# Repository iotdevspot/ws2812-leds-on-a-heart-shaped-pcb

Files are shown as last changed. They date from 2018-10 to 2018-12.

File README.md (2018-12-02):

# ws2812-leds-on-a-heart-shaped-pcb

### About the project
This is a WS2812 LED driver circuit with an ATTiny85 MCU. PCB and the LEDs are aligned to create a heart shape because it's a gift.  Unfortunately, I'm quite sort of time so the code is very basic and it has been created from the examples found on Adafruit's website. In the future I'll upload a newer version. This version is only capable for 4 basic effects witch can be selected with the left function button.

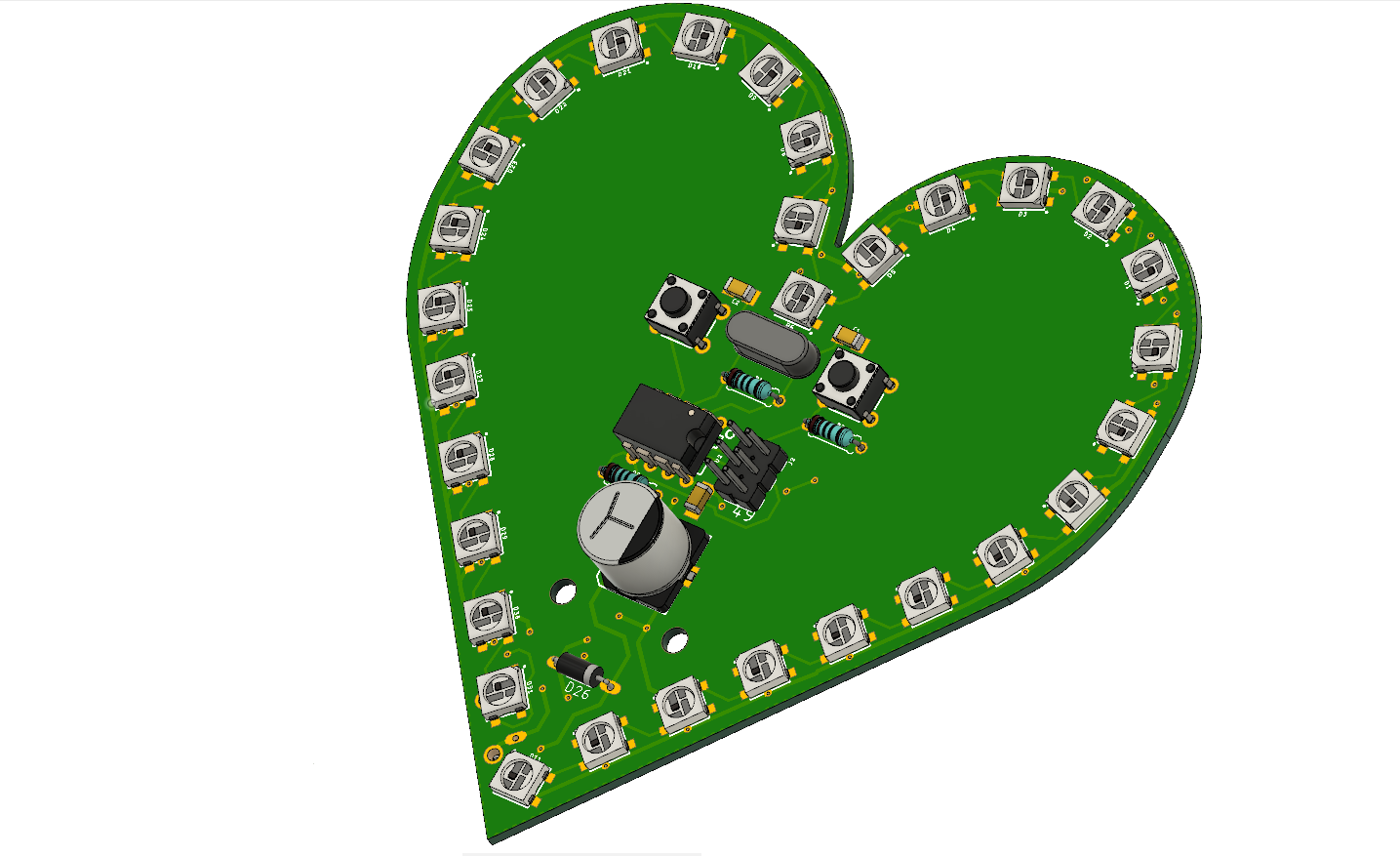
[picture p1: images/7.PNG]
image of the pcb


### Contents
* Gerber files (the version that I've sent to the fab house)
* Updated board layout and schematics
* 3D model can be found on my fusion360 gallery
* Code (Arduino sketch and hex)
* Datasheet
* Images of the result

### The following steps are required to deploy the provided .hex, or the Arduino sketch:
* Here is how to program ATTiny MCUs in Arduino IDE: [link](http://highlowtech.org/?p=1695)
* I've used external 16 MHz oscillator (AVR fuse settings needed + hex is compiled this way too) so it might be required but I assume it works on internal clock well too but code should be recompiled
* Code is based on Adafruit's [Neopixel libary and their example projects](https://learn.adafruit.com/adafruit-arduino-lesson-16-stepper-motors/breadboard-layout) so Adafruit's libary might be needed if you want to deploy it from the IDE.
* Finnaly the hex should be uploaded. You can do this by using IDE-s "Upload using programmer" option or .hex file can be uploaded throuh AVR Dude too. It's basically your choice...

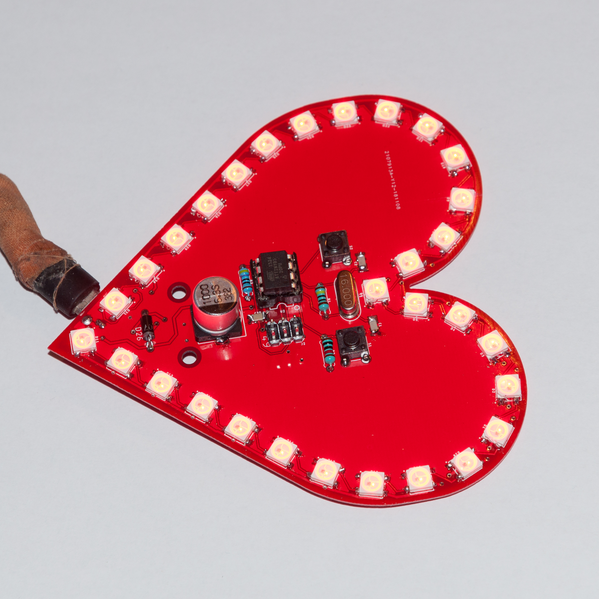
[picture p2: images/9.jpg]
image of the pcb


### ToDo

* 3D printed mounting for the two mounting holes
* Replace the full bascic code

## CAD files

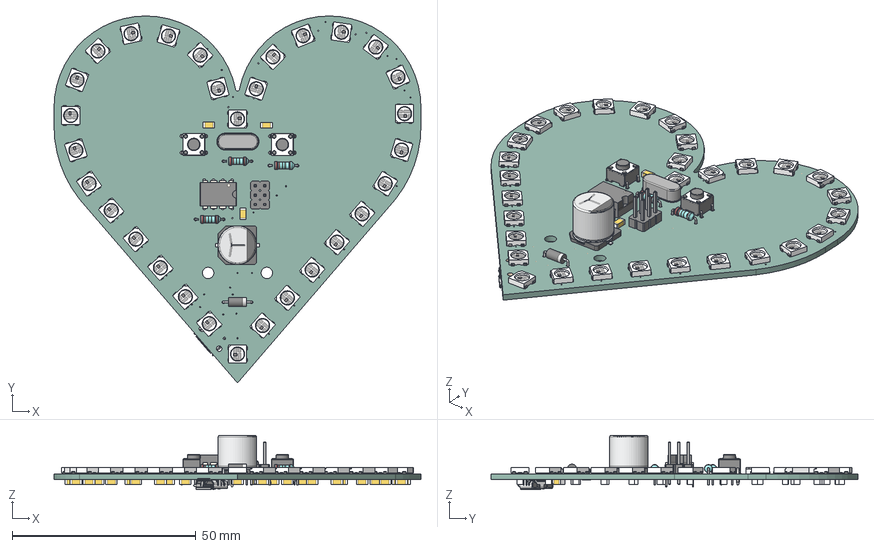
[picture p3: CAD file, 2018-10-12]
heart-shaped-smd-light-gift v12.step
100.0 x 100.0 x 14.8 mm
Board
100 nF x 33
WS2812B x 30
CONN_AVR_SPI_PROG_3X2PTH
CONN_USB_MICRO_FEM_GDND
D-7.5
16MHz
1000 uF
INPUT_MOMENTARY_SWITCH_SPST-PTH-6.0MM x 2
TINY45-20-DIP
SNAP-MALE x 2

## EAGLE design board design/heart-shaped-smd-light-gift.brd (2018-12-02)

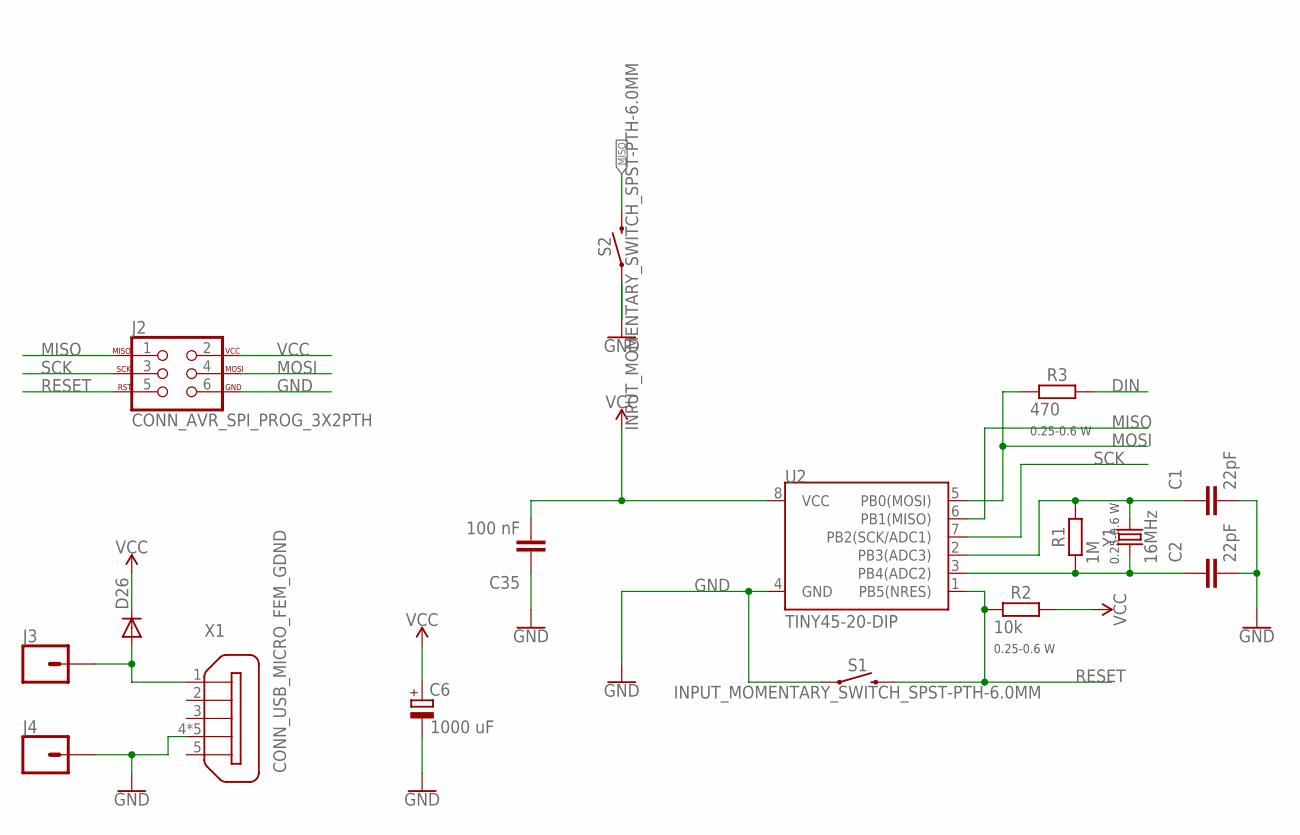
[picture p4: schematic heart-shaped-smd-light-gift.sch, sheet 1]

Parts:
C1, C2: 22pF; C1206I-C3216M
C6: 1000 uF; 153CLV-1010
C35: 100 nF; C1206I-C3216M
D26: DIODED-7.5; D-7.5
J2: CONN_AVR_SPI_PROG_3X2PTH; 2X3_S
J3, J4: CONN_01SNAP-MALE; SNAP-MALE
R1: 1M; 0207/7
R2: 10k; 0207/7
R3: 470; 0207/7
S1, S2: INPUT_MOMENTARY_SWITCH_SPST-PTH-6.0MM; TACTILE_SWITCH_PTH_6.0MM
U2: TINY45-20-DIP; DIP08
X1: CONN_USB_MICRO_FEM_GDND; ZX62D-B-5PA8
Y1: 16MHz; HC49US

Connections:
DIN: R3.2; also elsewhere on the board
GND: C1.2, C2.2, C6.-, C35.1, J2.6, J4.2, S1.1, S2.1, U2.4 (GND), X1.4, X1.S1 (4), X1.S2 (4), X1.S3 (4), X1.S4 (4); also elsewhere on the board
MISO: J2.1, S2.3 (2), U2.6 (PB1(MISO))
MOSI: J2.4, R3.1, U2.5 (PB0(MOSI))
unnamed: C2.1, R1.1, U2.3 (PB4(ADC2)), Y1.1
unnamed: C1.1, R1.2, U2.2 (PB3(ADC3)), Y1.2
unnamed: D26.A, J3.2, X1.1
RESET: J2.5, R2.1, S1.3 (2), U2.1 (PB5(NRES))
SCK: J2.3, U2.7 (PB2(SCK/ADC1))
VCC: C6.+, C35.2, D26.C, J2.2, R2.2, U2.8 (VCC); also elsewhere on the board

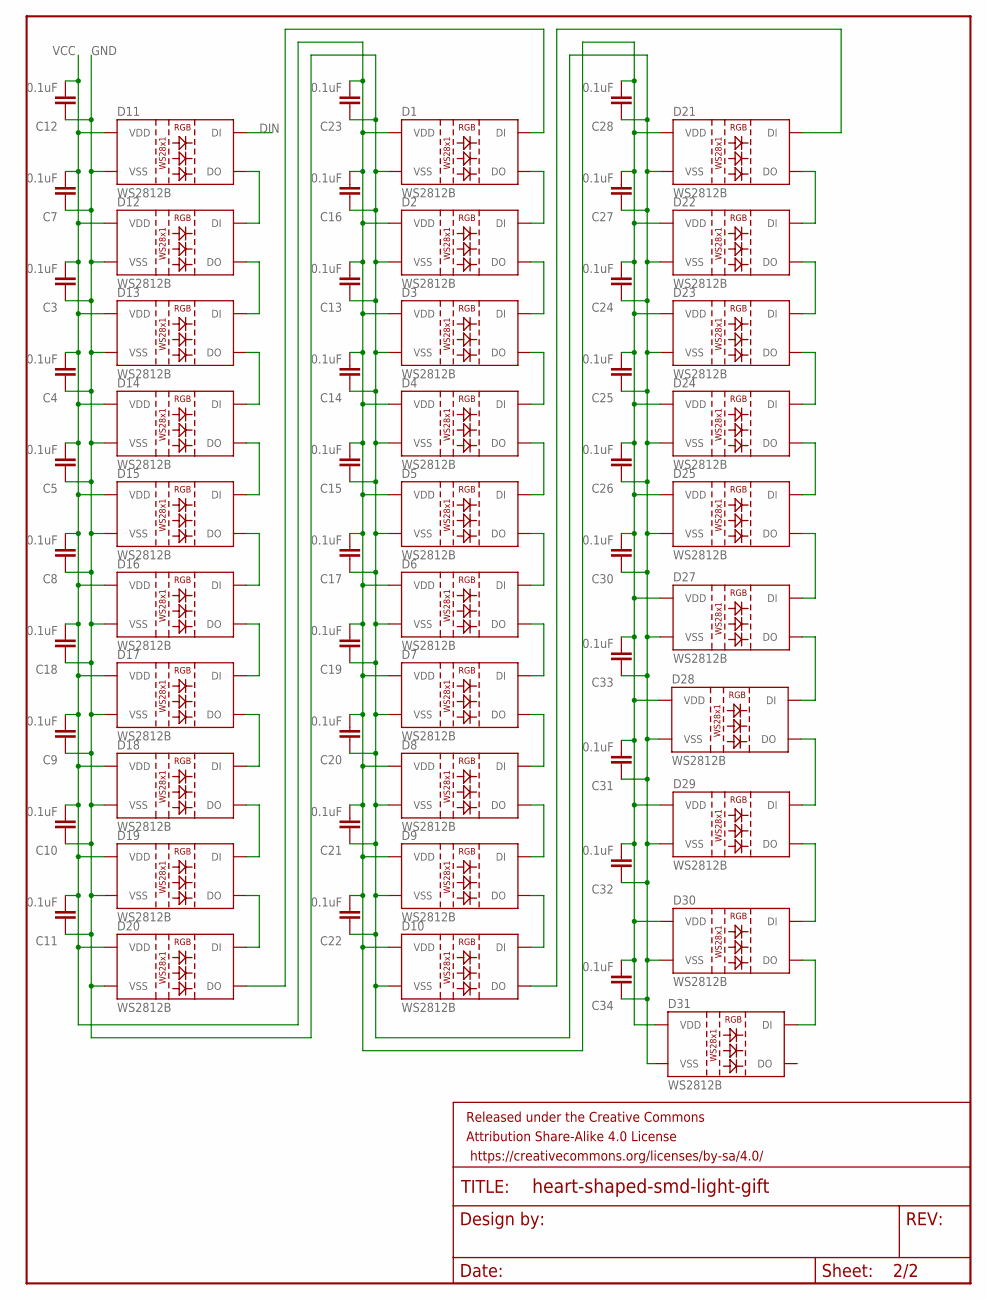
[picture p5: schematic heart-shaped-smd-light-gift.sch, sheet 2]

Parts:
C3, C4, C5, C7, C8, C9, C10, C11, C12, C13, C14, C15, C16, C17, C18, C19, C20, C21, C22, C23, C24, C25, C26, C27, C28, C30, C31, C32, C33, C34: 0.1uF; C1206I-C3216M
D1, D2, D3, D4, D5, D6, D7, D8, D9, D10, D11, D12, D13, D14, D15, D16, D17, D18, D19, D20, D21, D22, D23, D24, D25, D27, D28, D29, D30, D31: WS2812B
FRAME2: FRAME_LETTERNO_PACKAGE; DUMMY

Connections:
DIN: D11.4 (DI); also elsewhere on the board
DIN2: D10.2 (DO), D21.4 (DI)
GND: C3.1, C4.1, C5.1, C7.1, C8.1, C9.1, C10.1, C11.1, C12.1, C13.1, C14.1, C15.1, C16.1, C17.1, C18.1, C19.1, C20.1, C21.1, C22.1, C23.1, C24.1, C25.1, C26.1, C27.1, C28.1, C30.1, C31.1, C32.1, C33.1, C34.1, D1.3 (VSS), D2.3 (VSS), D3.3 (VSS), D4.3 (VSS), D5.3 (VSS), D6.3 (VSS), D7.3 (VSS), D8.3 (VSS), D9.3 (VSS), D10.3 (VSS), D11.3 (VSS), D12.3 (VSS), D13.3 (VSS), D14.3 (VSS), D15.3 (VSS), D16.3 (VSS), D17.3 (VSS), D18.3 (VSS), D19.3 (VSS), D20.3 (VSS), D21.3 (VSS), D22.3 (VSS), D23.3 (VSS), D24.3 (VSS), D25.3 (VSS), D27.3 (VSS), D28.3 (VSS), D29.3 (VSS), D30.3 (VSS), D31.3 (VSS); also elsewhere on the board
unnamed: D18.2 (DO), D19.4 (DI)
unnamed: D1.2 (DO), D2.4 (DI)
unnamed: D2.2 (DO), D3.4 (DI)
unnamed: D3.2 (DO), D4.4 (DI)
unnamed: D4.2 (DO), D5.4 (DI)
unnamed: D5.2 (DO), D6.4 (DI)
unnamed: D11.2 (DO), D12.4 (DI)
unnamed: D6.2 (DO), D7.4 (DI)
unnamed: D12.2 (DO), D13.4 (DI)
unnamed: D7.2 (DO), D8.4 (DI)
unnamed: D8.2 (DO), D9.4 (DI)
unnamed: D9.2 (DO), D10.4 (DI)
unnamed: D1.4 (DI), D20.2 (DO)
unnamed: D21.2 (DO), D22.4 (DI)
unnamed: D13.2 (DO), D14.4 (DI)
unnamed: D14.2 (DO), D15.4 (DI)
unnamed: D22.2 (DO), D23.4 (DI)
unnamed: D15.2 (DO), D16.4 (DI)
unnamed: D16.2 (DO), D17.4 (DI)
unnamed: D17.2 (DO), D18.4 (DI)
unnamed: D19.2 (DO), D20.4 (DI)
unnamed: D23.2 (DO), D24.4 (DI)
unnamed: D24.2 (DO), D25.4 (DI)
unnamed: D25.2 (DO), D27.4 (DI)
unnamed: D27.2 (DO), D28.4 (DI)
unnamed: D28.2 (DO), D29.4 (DI)
unnamed: D29.2 (DO), D30.4 (DI)
unnamed: D30.2 (DO), D31.4 (DI)
VCC: C3.2, C4.2, C5.2, C7.2, C8.2, C9.2, C10.2, C11.2, C12.2, C13.2, C14.2, C15.2, C16.2, C17.2, C18.2, C19.2, C20.2, C21.2, C22.2, C23.2, C24.2, C25.2, C26.2, C27.2, C28.2, C30.2, C31.2, C32.2, C33.2, C34.2, D1.1 (VDD), D2.1 (VDD), D3.1 (VDD), D4.1 (VDD), D5.1 (VDD), D6.1 (VDD), D7.1 (VDD), D8.1 (VDD), D9.1 (VDD), D10.1 (VDD), D11.1 (VDD), D12.1 (VDD), D13.1 (VDD), D14.1 (VDD), D15.1 (VDD), D16.1 (VDD), D17.1 (VDD), D18.1 (VDD), D19.1 (VDD), D20.1 (VDD), D21.1 (VDD), D22.1 (VDD), D23.1 (VDD), D24.1 (VDD), D25.1 (VDD), D27.1 (VDD), D28.1 (VDD), D29.1 (VDD), D30.1 (VDD), D31.1 (VDD); also elsewhere on the board

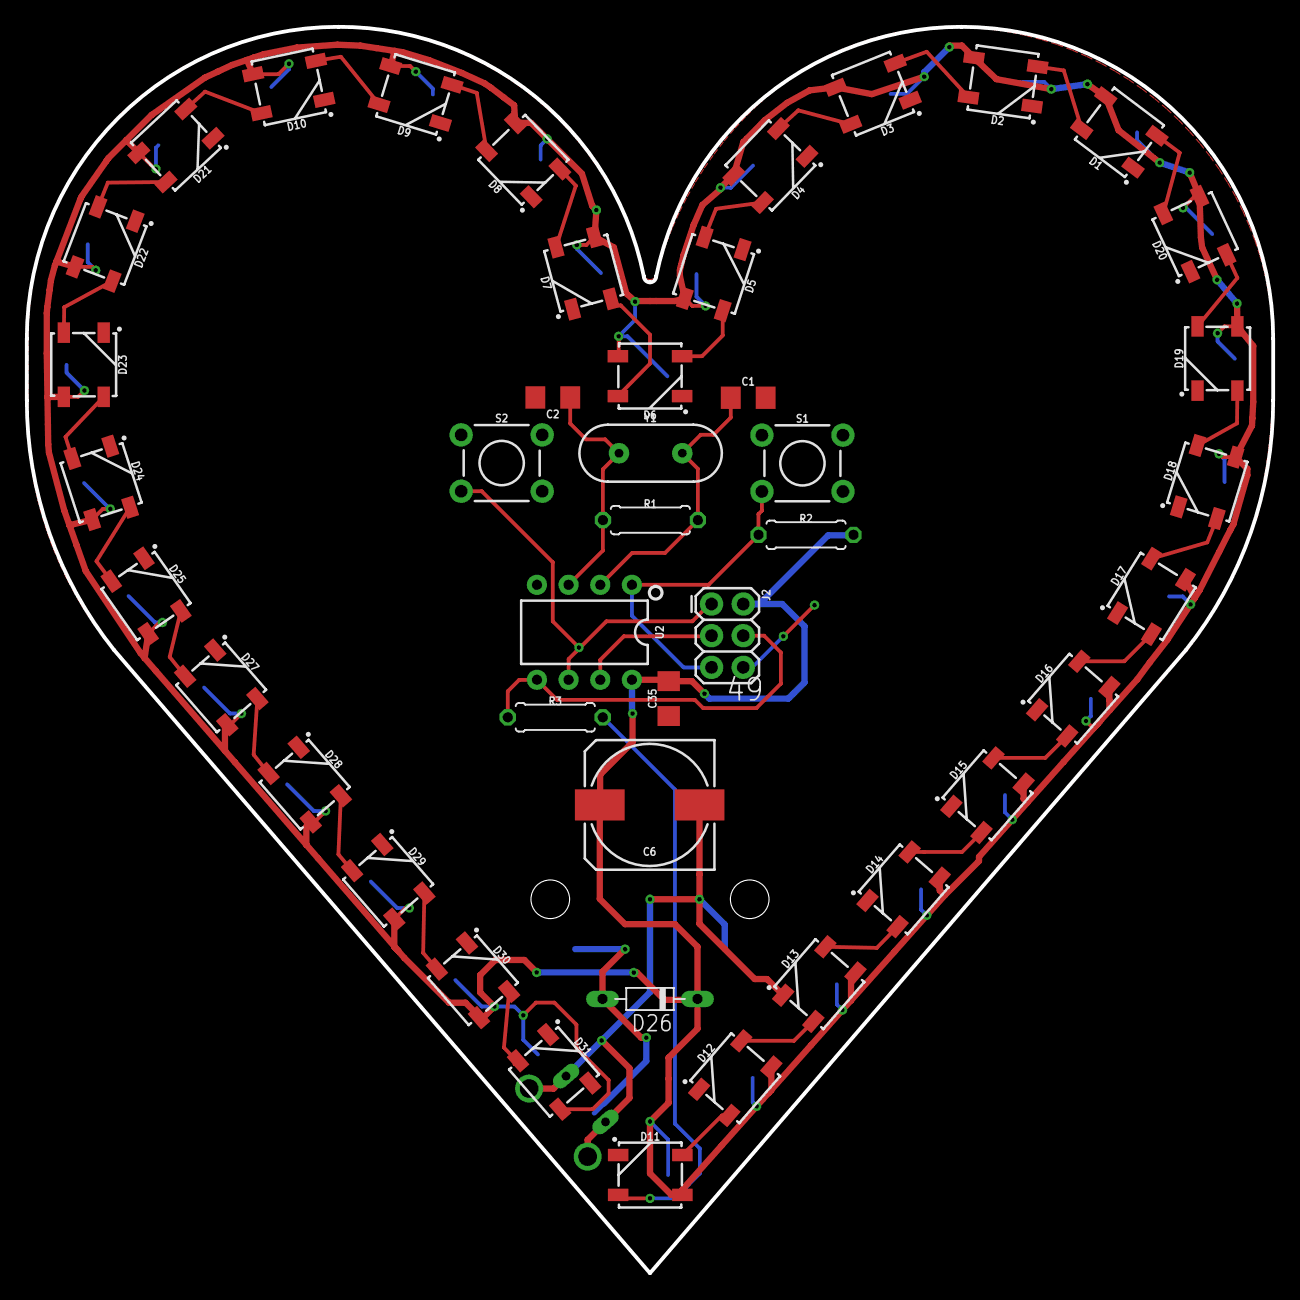
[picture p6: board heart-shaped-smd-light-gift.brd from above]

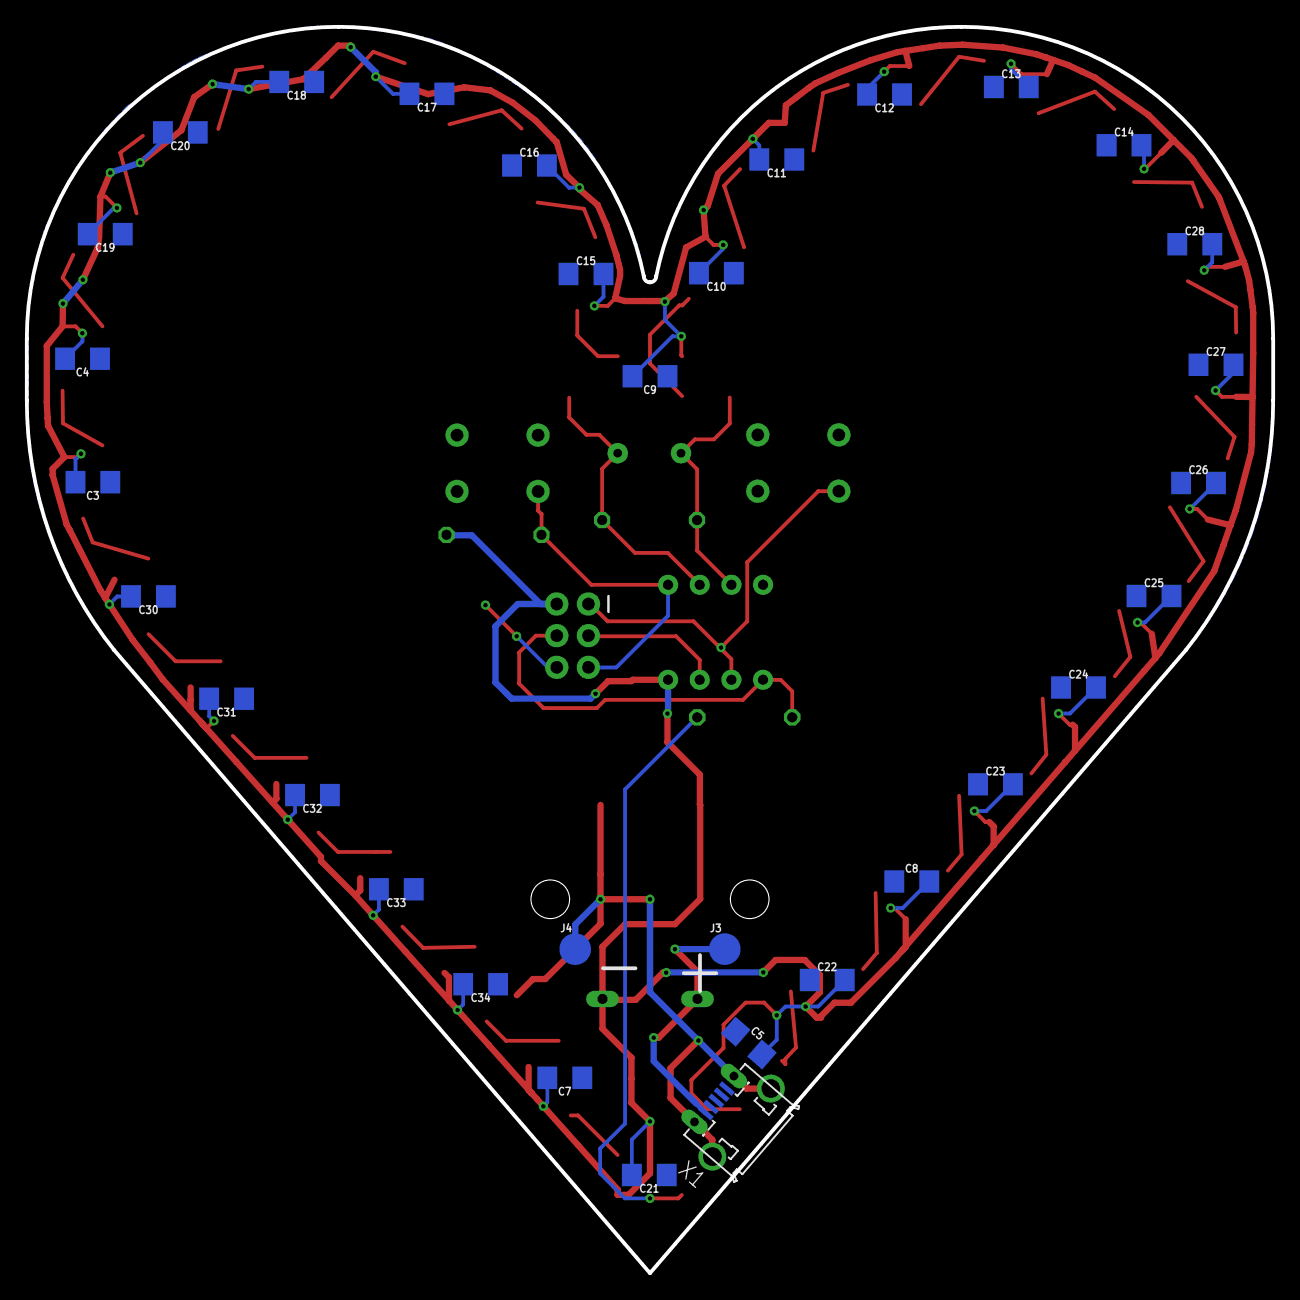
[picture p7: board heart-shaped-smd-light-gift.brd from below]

Board: 2 copper layers, 100.0 x 100.0 mm, 77 parts (33 on the bottom side), 39 nets.

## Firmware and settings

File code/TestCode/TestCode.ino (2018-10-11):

#include <Adafruit_NeoPixel.h>
#ifdef __AVR__
  #include <avr/power.h>
#endif

const int PIXEL_COUNT = 30;;
const int PIXEL_PIN = 0;
const int BUTTON_PIN = 1;

bool oldState = HIGH;
int showType = 0;

Adafruit_NeoPixel strip = Adafruit_NeoPixel(PIXEL_COUNT, PIXEL_PIN, NEO_GRB + NEO_KHZ800);
 

void setup() {
  #if defined (__AVR_ATtiny85__)
    if (F_CPU == 16000000) clock_prescale_set(clock_div_1);
  #endif
  pinMode(BUTTON_PIN, INPUT_PULLUP);
  strip.begin();
  strip.show();
}

void loop() {
  bool newState = digitalRead(BUTTON_PIN);
  
  if (newState == LOW && oldState == HIGH) {
    delay(20);
    newState = digitalRead(BUTTON_PIN);
    if (newState == LOW) {
      showType++;
      if (showType > 4)
        showType=0;
      startShow(showType);
    }
  }

  oldState = newState;
}


void startShow(int i) {
  switch(i){
    case 0: colorWipe(strip.Color(0, 0, 0), 50);    // Black/off
            break;
    case 1: colorWipe(strip.Color(255, 0, 0), 50);  // Red
            break;
    case 2: colorWipe(strip.Color(0, 255, 0), 50);  // Green
            break;
    case 3: colorWipe(strip.Color(0, 0, 255), 50);  // Blue
            break;
    case 4: rainbow(20);
            break;
    case 5: rainbowCycle(20);
            break;
  }
}

// Fill the dots one after the other with a color
void colorWipe(uint32_t c, uint8_t wait) {
  for(uint16_t i=0; i<strip.numPixels(); i++) {
    strip.setPixelColor(i, c);
    strip.show();
    delay(wait);
  }
}

void rainbow(uint8_t wait) {
  uint16_t i, j;

  for(j=0; j<256; j++) {
    for(i=0; i<strip.numPixels(); i++) {
      strip.setPixelColor(i, Wheel((i+j) & 255));
    }
    strip.show();
    delay(wait);
  }
}

// Slightly different, this makes the rainbow equally distributed throughout
void rainbowCycle(uint8_t wait) {
  uint16_t i, j;

  for(j=0; j<256*5; j++) { // 5 cycles of all colors on wheel
    for(i=0; i< strip.numPixels(); i++) {
      strip.setPixelColor(i, Wheel(((i * 256 / strip.numPixels()) + j) & 255));
    }
    strip.show();
    delay(wait);
  }
}

// Input a value 0 to 255 to get a color value.
// The colours are a transition r - g - b - back to r.
uint32_t Wheel(byte WheelPos) {
  WheelPos = 255 - WheelPos;
  if(WheelPos < 85) {
    return strip.Color(255 - WheelPos * 3, 0, WheelPos * 3);
  }
  if(WheelPos < 170) {
    WheelPos -= 85;
    return strip.Color(0, WheelPos * 3, 255 - WheelPos * 3);
  }
  WheelPos -= 170;
  return strip.Color(WheelPos * 3, 255 - WheelPos * 3, 0);
}

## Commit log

2018-10-11 Compiled code for an ATTiny MCU-s with external 16 MHz oscillator
    [heart-shaped-smd-light-gift.brd, heart-shaped-smd-light-gift.sch]
2018-10-12 3D model of the PCB added
    [heart-shaped-smd-light-gift v12.step]
2018-12-02 Updated Eagle design files and gerbers
    [heart-shaped-smd-light-gift.brd]

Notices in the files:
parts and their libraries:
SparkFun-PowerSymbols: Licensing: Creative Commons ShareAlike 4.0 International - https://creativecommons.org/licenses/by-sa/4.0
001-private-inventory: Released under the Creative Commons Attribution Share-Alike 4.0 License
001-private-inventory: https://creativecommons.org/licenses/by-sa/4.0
